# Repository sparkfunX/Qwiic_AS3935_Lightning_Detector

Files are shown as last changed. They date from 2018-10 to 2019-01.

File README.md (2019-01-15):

SparkX Qwiic AS3935 Lightning Detector
========================================

Qwiic AS3925 Lightning Detector (https://www.sparkfun.com/products/15057)

[*SparkX Qwiic AS3935 Lightning Detector (SPX-15057)*](https://www.sparkfun.com/products/15057)

Repository Contents
-------------------

* **/Buzzard Labels** - Silkscreen labels for Qwiic AS3935
* **/Documentation** - Data sheets, additional product information
* **/Hardware** - Eagle design files (.brd, .sch)

Documentation
--------------
* **[Installing an Arduino Library](https://learn.sparkfun.com/tutorials/installing-an-arduino-library/)** - Basic instructions on installing an Arduino library
* **[Library](https://github.com/sparkfun/SparkFun_AS3935_Lightning_Detector_Library)** - Arduino library for the Qwiic AS3935 Lightning Detector

License Information
-------------------

This product is _**open source**_! 

Please review the LICENSE.md file for license information.

If you have any questions or concerns on licensing, please contact techsupport@sparkfun.com.

Please use, reuse, and modify these files as you see fit. Please maintain attribution to SparkFun Electronics and release under the same license.

Distributed as-is; no warranty is given.

- Your friends at SparkFun.

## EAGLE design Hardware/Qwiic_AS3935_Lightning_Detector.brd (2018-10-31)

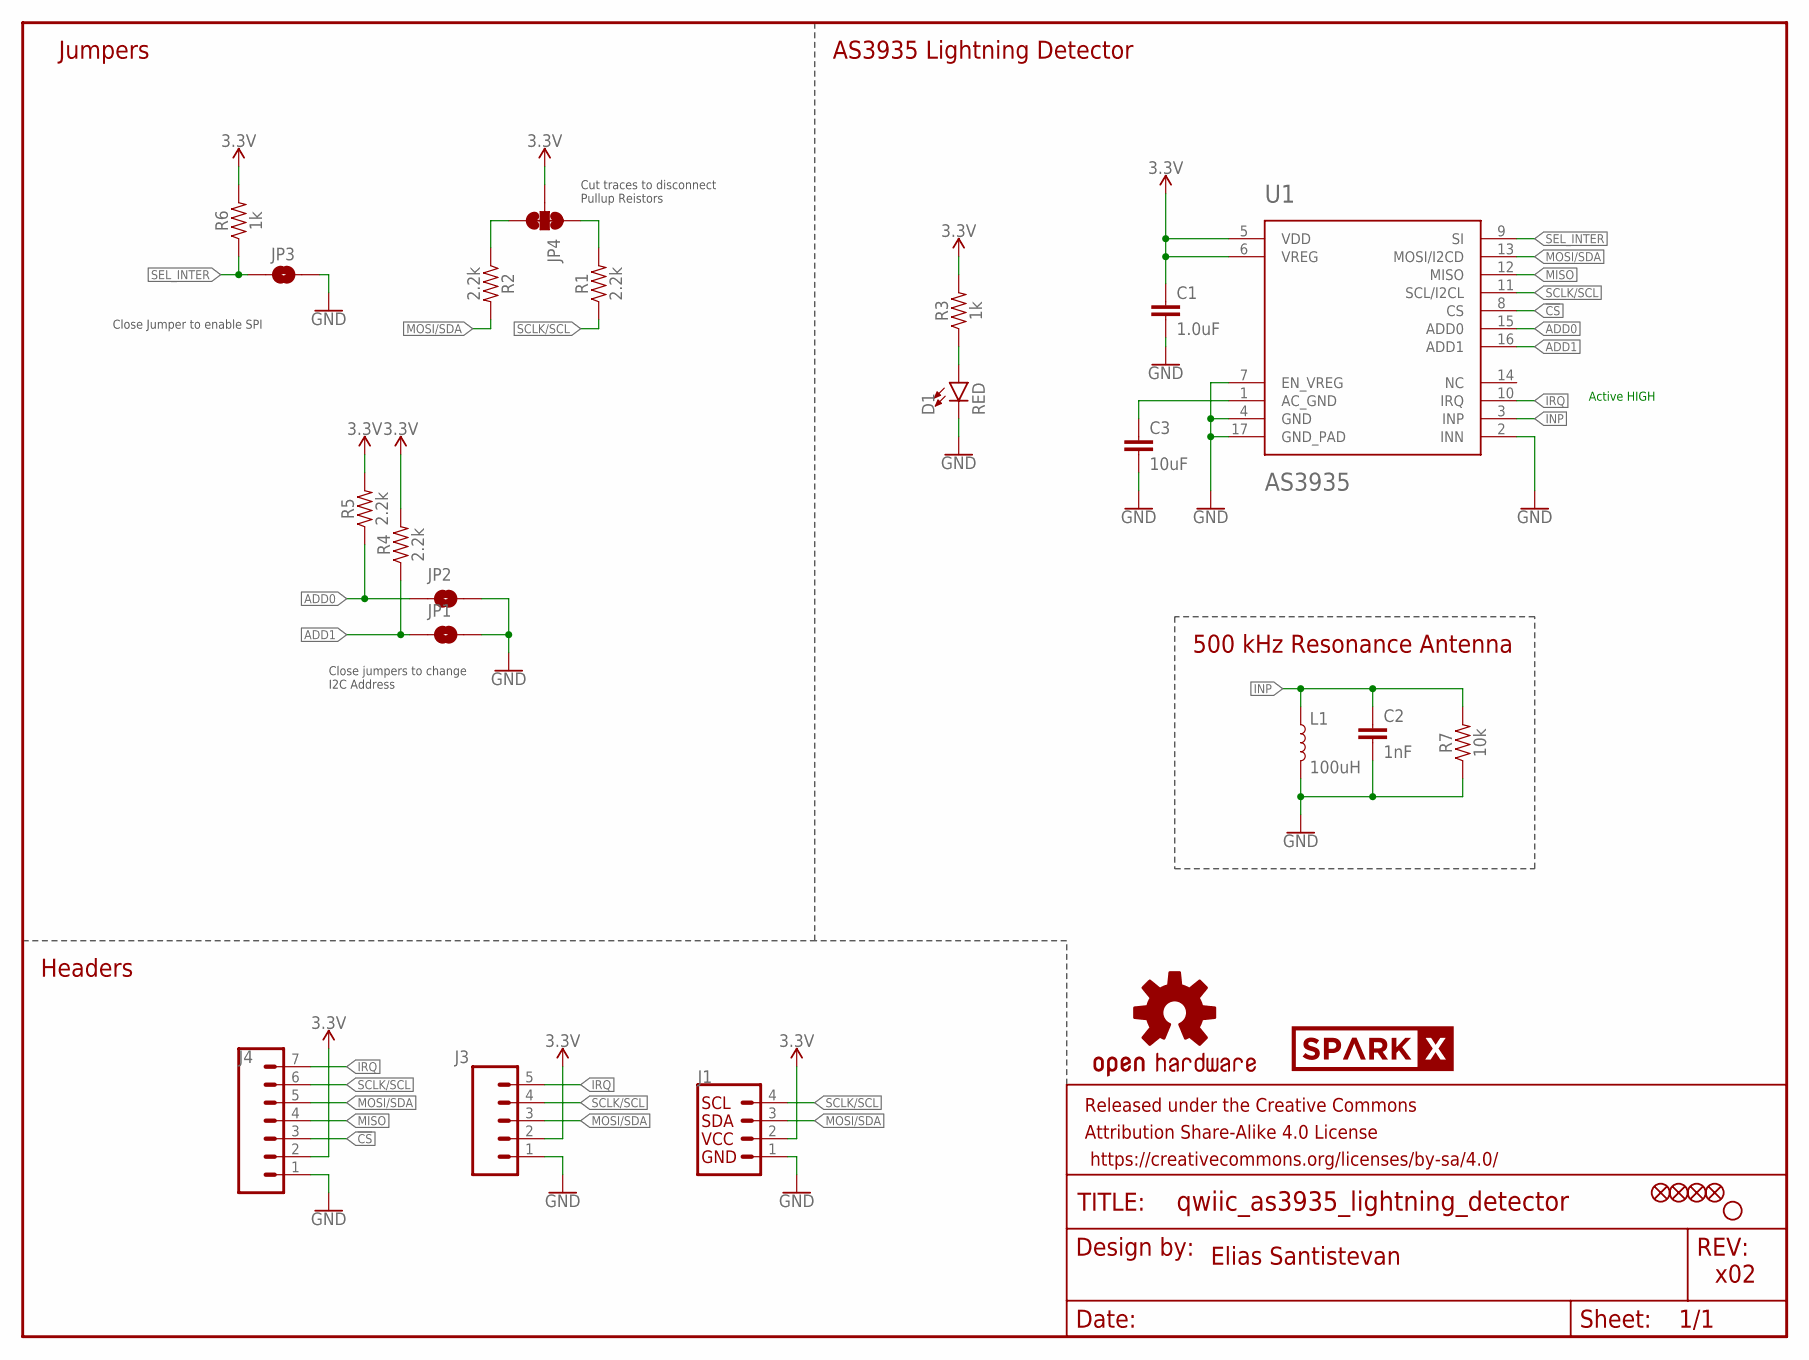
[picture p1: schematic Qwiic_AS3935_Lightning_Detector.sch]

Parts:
C1: 1.0uF; 0603
C2: 1nF; 0603
C3: 10uF; 0603
D1: RED; LED-0603
FD1, FD2, FD3, FD4: FIDUCIAL1X2; FIDUCIAL-1X2
FRAME1: FRAME-LETTER; CREATIVE_COMMONS
H1: STAND-OFFTIGHT; STAND-OFF-TIGHT
J1: QWIIC_CONNECTORJS-1MM; 1X04_1MM_RA
J3: CONN_05NO_SILK; 1X05_NO_SILK
J4: CONN_07NO_SILK; 1X07_NO_SILK
JP1, JP2, JP3: JUMPER-SMT_2_NO_SILK; SMT-JUMPER_2_NO_SILK
JP4: JUMPER-SMT_3_2-NC_TRACE_SILK; SMT-JUMPER_3_2-NC_TRACE_SILK
L1: 100uH; MA5532-AE
LOGO1: OSHW-LOGOS; OSHW-LOGO-S
R1, R2, R4, R5: 2.2k; 0603
R3, R6: 1k; 0603
R7: 10k; 0603
U1: AS3935; 16LD_MLPQ
U$1: SPARKX-LOGO2; SPARKX-TINY

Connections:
3.3V: C1.1, J1.2, J3.2, J4.2, JP4.2, R3.2, R4.2, R5.2, R6.2, U1.5 (VDD), U1.6 (VREG)
!CS: J4.3, U1.8 (CS)
ADD0: JP2.1, R5.1, U1.15 (ADD0)
ADD1: JP1.1, R4.1, U1.16 (ADD1)
GND: C1.2, C2.2, C3.2, D1.C, J1.1, J3.1, J4.1, JP1.2, JP2.2, JP3.2, L1.2, R7.1, U1.2 (INN), U1.4 (GND), U1.7 (EN_VREG), U1.17 (GND_PAD)
INP: C2.1, L1.1, R7.2, U1.3 (INP)
IRQ: J3.5, J4.7, U1.10 (IRQ)
MISO: J4.4, U1.12 (MISO)
MOSI/SDA: J1.3, J3.3, J4.5, R2.2, U1.13 (MOSI/I2CD)
unnamed: D1.A, R3.1
unnamed: C3.1, U1.1 (AC_GND)
unnamed: JP4.1, R1.2
unnamed: JP4.3, R2.1
SCLK/SCL: J1.4, J3.4, J4.6, R1.1, U1.11 (SCL/I2CL)
SEL_INTER: JP3.1, R6.1, U1.9 (SI)

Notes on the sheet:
Elias Santistevan
x02
Active HIGH
AS3935 Lightning Detector
Jumpers
Headers
500 kHz Resonance Antenna
Close Jumper to enable SPI
Cut traces to disconnect Pullup Reistors
Close jumpers to change I2C Address

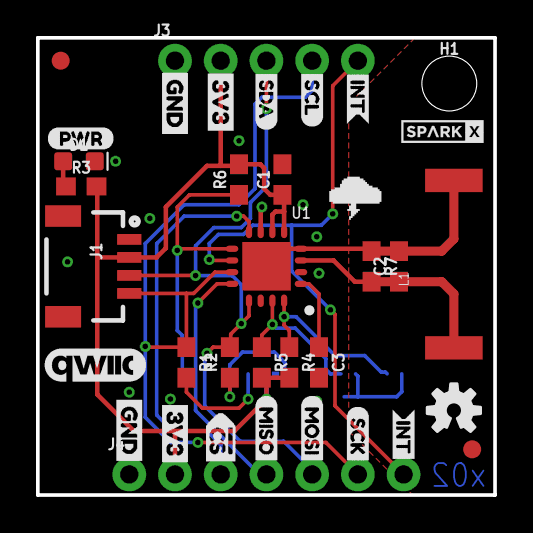
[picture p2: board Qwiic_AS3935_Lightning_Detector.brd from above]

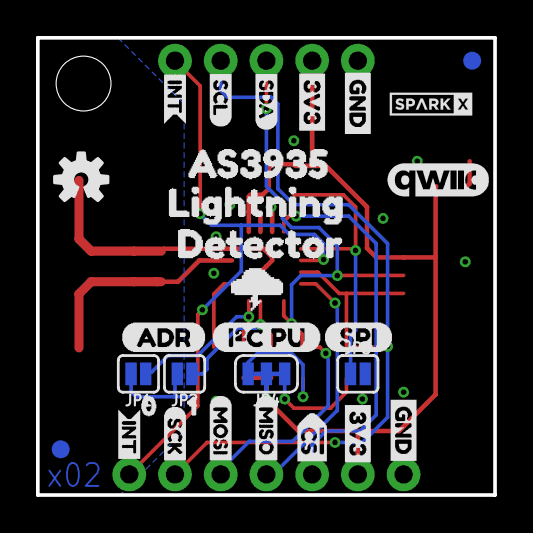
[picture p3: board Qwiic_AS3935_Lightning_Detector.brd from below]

Board: 2 copper layers, 25.4 x 25.4 mm, 67 parts (30 on the bottom side), 15 nets.

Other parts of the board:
U$2: SPARKX-TINY
U$3, U$4: QWIIC_COPYRIGHT_SMALL
U$5, U$40: ##0
U$6: AS39350
U$7: LIGHTNING0
U$8, U$9, U$10, U$38: GND-03
U$11: CS#-<]-04
U$12, U$13: MISO-(]-03
U$14, U$15, U$24, U$29: INT0
U$16, U$22: MOSI-(]-03
U$17, U$18, U$20, U$21: 3V3-03
U$19, U$23: SCK-(]-03
U$25, U$26: SDA0
U$27, U$28: SCL0
U$30: #CS0
U$31: OSHW-LOGO-S
U$32: PWR-()-03
U$33: ADR-()-04
U$34: I#C_PU0
U$35: SPI0
U$36: 10
U$37: 00
U$39: DETECTOR0

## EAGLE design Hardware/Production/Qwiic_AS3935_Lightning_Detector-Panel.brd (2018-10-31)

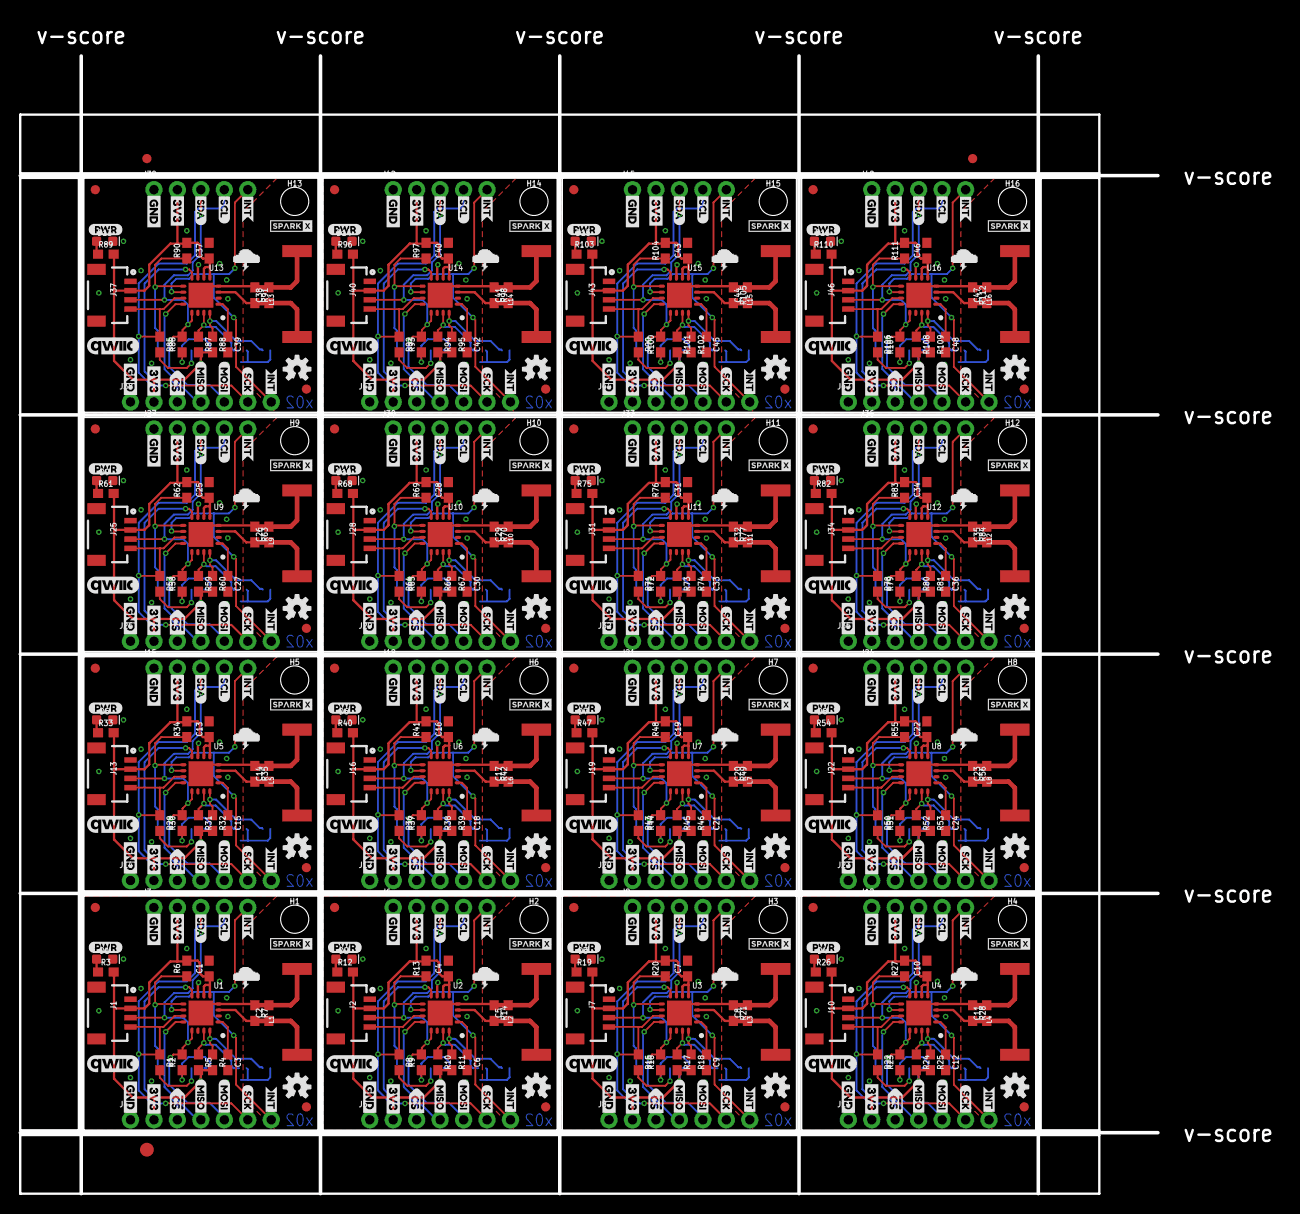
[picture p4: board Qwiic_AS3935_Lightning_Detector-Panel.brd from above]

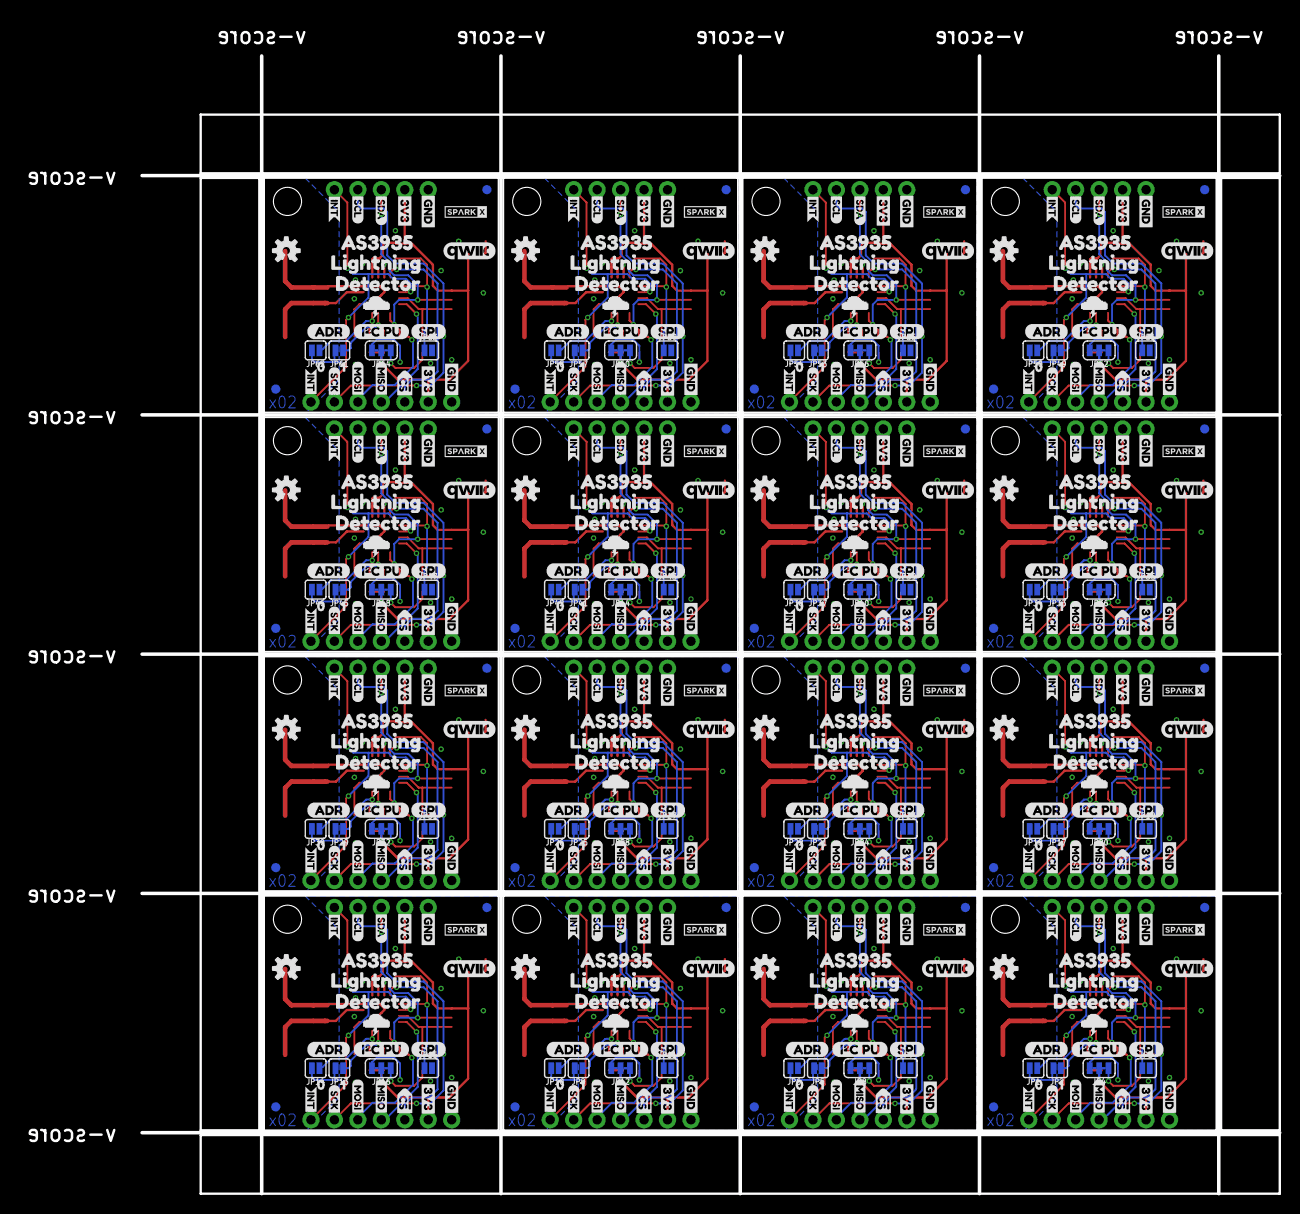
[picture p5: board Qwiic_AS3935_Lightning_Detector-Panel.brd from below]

Board: 2 copper layers, 123.2 x 123.2 mm, 1059 parts (480 on the bottom side), 240 nets.

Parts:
C1, C4, C7, C10, C13, C16, C19, C22, C25, C28, C31, C34, C37, C40, C43, C46: 1.0uF; 0603
C2, C5, C8, C11, C14, C17, C20, C23, C26, C29, C32, C35, C38, C41, C44, C47: 1nF; 0603
C3, C6, C9, C12, C15, C18, C21, C24, C27, C30, C33, C36, C39, C42, C45, C48: 10uF; 0603
D1, D2, D3, D4, D5, D6, D7, D8, D9, D10, D11, D12, D13, D14, D15, D16: RED; LED-0603
E$1, E$2: FIDUCIAL-1X2
E$3: FIDUCIAL-1.5X3
FD1, FD2, FD3, FD4, FD5, FD6, FD7, FD8, FD9, FD10, FD11, FD12, FD13, FD14, FD15, FD16, FD17, FD18, FD19, FD20, FD21, FD22, FD23, FD24, FD25, FD26, FD27, FD28, FD29, FD30, FD31, FD32, FD33, FD34, FD35, FD36, FD37, FD38, FD39, FD40, FD41, FD42, FD43, FD44, FD45, FD46, FD47, FD48, FD49, FD50, FD51, FD52, FD53, FD54, FD55, FD56, FD57, FD58, FD59, FD60, FD61, FD62, FD63, FD64: FIDUCIAL1X2; FIDUCIAL-1X2
H1, H2, H3, H4, H5, H6, H7, H8, H9, H10, H11, H12, H13, H14, H15, H16: STAND-OFFTIGHT; STAND-OFF-TIGHT
J1, J2, J7, J10, J13, J16, J19, J22, J25, J28, J31, J34, J37, J40, J43, J46: 1X04_1MM_RA
J3, J6, J9, J12, J15, J18, J21, J24, J27, J30, J33, J36, J39, J42, J45, J48: 1X05_NO_SILK
J4, J5, J8, J11, J14, J17, J20, J23, J26, J29, J32, J35, J38, J41, J44, J47: 1X07_NO_SILK
JP1, JP2, JP3, JP5, JP6, JP7, JP9, JP10, JP11, JP13, JP14, JP15, JP17, JP18, JP19, JP21, JP22, JP23, JP25, JP26, JP27, JP29, JP30, JP31, JP33, JP34, JP35, JP37, JP38, JP39, JP41, JP42, JP43, JP45, JP46, JP47, JP49, JP50, JP51, JP53, JP54, JP55, JP57, JP58, JP59, JP61, JP62, JP63: JUMPER-SMT_2_NO_SILK; SMT-JUMPER_2_NO_SILK
JP4, JP8, JP12, JP16, JP20, JP24, JP28, JP32, JP36, JP40, JP44, JP48, JP52, JP56, JP60, JP64: JUMPER-SMT_3_2-NC_TRACE_SILK; SMT-JUMPER_3_2-NC_TRACE_SILK
L1, L2, L3, L4, L5, L6, L7, L8, L9, L10, L11, L12, L13, L14, L15, L16: 100uH; MA5532-AE
LOGO1, LOGO2, LOGO3, LOGO4, LOGO5, LOGO6, LOGO7, LOGO8, LOGO9, LOGO10, LOGO11, LOGO12, LOGO13, LOGO14, LOGO15, LOGO16: OSHW-LOGOS; OSHW-LOGO-S
R1, R2, R4, R5, R8, R9, R10, R11, R15, R16, R17, R18, R22, R23, R24, R25, R29, R30, R31, R32, R36, R37, R38, R39, R43, R44, R45, R46, R50, R51, R52, R53, R57, R58, R59, R60, R64, R65, R66, R67, R71, R72, R73, R74, R78, R79, R80, R81, R85, R86, R87, R88, R92, R93, R94, R95, R99, R100, R101, R102, R106, R107, R108, R109: 2.2k; 0603
R3, R6, R12, R13, R19, R20, R26, R27, R33, R34, R40, R41, R47, R48, R54, R55, R61, R62, R68, R69, R75, R76, R82, R83, R89, R90, R96, R97, R103, R104, R110, R111: 1k; 0603
R7, R14, R21, R28, R35, R42, R49, R56, R63, R70, R77, R84, R91, R98, R105, R112: 10k; 0603
U1, U2, U3, U4, U5, U6, U7, U8, U9, U10, U11, U12, U13, U14, U15, U16: AS3935; 16LD_MLPQ
U$1, U$41, U$81, U$121, U$161, U$201, U$241, U$281, U$321, U$361, U$401, U$441, U$481, U$521, U$561, U$601: SPARKX-LOGO2; SPARKX-TINY
U$2, U$42, U$82, U$122, U$162, U$202, U$242, U$282, U$322, U$362, U$402, U$442, U$482, U$522, U$562, U$602: SPARKX-TINY
U$3, U$4, U$43, U$44, U$83, U$84, U$123, U$124, U$163, U$164, U$203, U$204, U$243, U$244, U$283, U$284, U$323, U$324, U$363, U$364, U$403, U$404, U$443, U$444, U$483, U$484, U$523, U$524, U$563, U$564, U$603, U$604: QWIIC_COPYRIGHT_SMALL
U$5, U$40, U$67, U$68, U$107, U$108, U$147, U$148, U$187, U$188, U$227, U$228, U$267, U$268, U$307, U$308, U$347, U$348, U$387, U$388, U$427, U$428, U$467, U$468, U$507, U$508, U$547, U$548, U$587, U$588, U$627, U$628: ##0
U$6, U$64, U$104, U$144, U$184, U$224, U$264, U$304, U$344, U$384, U$424, U$464, U$504, U$544, U$584, U$624: AS39350
U$7, U$65, U$105, U$145, U$185, U$225, U$265, U$305, U$345, U$385, U$425, U$465, U$505, U$545, U$585, U$625: LIGHTNING0
U$8, U$9, U$10, U$38, U$45, U$46, U$63, U$69, U$85, U$86, U$103, U$109, U$125, U$126, U$143, U$149, U$165, U$166, U$183, U$189, U$205, U$206, U$223, U$229, U$245, U$246, U$263, U$269, U$285, U$286, U$303, U$309, U$325, U$326, U$343, U$349, U$365, U$366, U$383, U$389, U$405, U$406, U$423, U$429, U$445, U$446, U$463, U$469, U$485, U$486, U$503, U$509, U$525, U$526, U$543, U$549, U$565, U$566, U$583, U$589, U$605, U$606, U$623, U$629: GND-03
U$11, U$70, U$110, U$150, U$190, U$230, U$270, U$310, U$350, U$390, U$430, U$470, U$510, U$550, U$590, U$630: CS#-<]-04
U$12, U$13, U$47, U$72, U$87, U$112, U$127, U$152, U$167, U$192, U$207, U$232, U$247, U$272, U$287, U$312, U$327, U$352, U$367, U$392, U$407, U$432, U$447, U$472, U$487, U$512, U$527, U$552, U$567, U$592, U$607, U$632: MISO-(]-03
U$14, U$15, U$24, U$29, U$74, U$75, U$76, U$77, U$114, U$115, U$116, U$117, U$154, U$155, U$156, U$157, U$194, U$195, U$196, U$197, U$234, U$235, U$236, U$237, U$274, U$275, U$276, U$277, U$314, U$315, U$316, U$317, U$354, U$355, U$356, U$357, U$394, U$395, U$396, U$397, U$434, U$435, U$436, U$437, U$474, U$475, U$476, U$477, U$514, U$515, U$516, U$517, U$554, U$555, U$556, U$557, U$594, U$595, U$596, U$597, U$634, U$635, U$636, U$637: INT0
U$16, U$22, U$71, U$78, U$111, U$118, U$151, U$158, U$191, U$198, U$231, U$238, U$271, U$278, U$311, U$318, U$351, U$358, U$391, U$398, U$431, U$438, U$471, U$478, U$511, U$518, U$551, U$558, U$591, U$598, U$631, U$638: MOSI-(]-03
U$17, U$18, U$20, U$21, U$48, U$49, U$50, U$51, U$88, U$89, U$90, U$91, U$128, U$129, U$130, U$131, U$168, U$169, U$170, U$171, U$208, U$209, U$210, U$211, U$248, U$249, U$250, U$251, U$288, U$289, U$290, U$291, U$328, U$329, U$330, U$331, U$368, U$369, U$370, U$371, U$408, U$409, U$410, U$411, U$448, U$449, U$450, U$451, U$488, U$489, U$490, U$491, U$528, U$529, U$530, U$531, U$568, U$569, U$570, U$571, U$608, U$609, U$610, U$611: 3V3-03
U$19, U$23, U$73, U$79, U$113, U$119, U$153, U$159, U$193, U$199, U$233, U$239, U$273, U$279, U$313, U$319, U$353, U$359, U$393, U$399, U$433, U$439, U$473, U$479, U$513, U$519, U$553, U$559, U$593, U$599, U$633, U$639: SCK-(]-03
U$25, U$26, U$52, U$53, U$92, U$93, U$132, U$133, U$172, U$173, U$212, U$213, U$252, U$253, U$292, U$293, U$332, U$333, U$372, U$373, U$412, U$413, U$452, U$453, U$492, U$493, U$532, U$533, U$572, U$573, U$612, U$613: SDA0
U$27, U$28, U$54, U$55, U$94, U$95, U$134, U$135, U$174, U$175, U$214, U$215, U$254, U$255, U$294, U$295, U$334, U$335, U$374, U$375, U$414, U$415, U$454, U$455, U$494, U$495, U$534, U$535, U$574, U$575, U$614, U$615: SCL0
U$30, U$80, U$120, U$160, U$200, U$240, U$280, U$320, U$360, U$400, U$440, U$480, U$520, U$560, U$600, U$640: #CS0
U$31, U$56, U$96, U$136, U$176, U$216, U$256, U$296, U$336, U$376, U$416, U$456, U$496, U$536, U$576, U$616: OSHW-LOGO-S
U$32, U$57, U$97, U$137, U$177, U$217, U$257, U$297, U$337, U$377, U$417, U$457, U$497, U$537, U$577, U$617: PWR-()-03
U$33, U$58, U$98, U$138, U$178, U$218, U$258, U$298, U$338, U$378, U$418, U$458, U$498, U$538, U$578, U$618: ADR-()-04
U$34, U$59, U$99, U$139, U$179, U$219, U$259, U$299, U$339, U$379, U$419, U$459, U$499, U$539, U$579, U$619: I#C_PU0
U$35, U$60, U$100, U$140, U$180, U$220, U$260, U$300, U$340, U$380, U$420, U$460, U$500, U$540, U$580, U$620: SPI0
U$36, U$61, U$101, U$141, U$181, U$221, U$261, U$301, U$341, U$381, U$421, U$461, U$501, U$541, U$581, U$621: 10
U$37, U$62, U$102, U$142, U$182, U$222, U$262, U$302, U$342, U$382, U$422, U$462, U$502, U$542, U$582, U$622: 00
U$39, U$66, U$106, U$146, U$186, U$226, U$266, U$306, U$346, U$386, U$426, U$466, U$506, U$546, U$586, U$626: DETECTOR0

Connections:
3.3V: C1.1, J1.2, J3.2, J4.2, JP4.2, R3.2, R4.2, R5.2, R6.2, U1.5, U1.6
3.3V1: C4.1, J2.2, J5.2, J6.2, JP8.2, R10.2, R11.2, R12.2, R13.2, U2.5, U2.6
3.3V2: C7.1, J7.2, J8.2, J9.2, JP12.2, R17.2, R18.2, R19.2, R20.2, U3.5, U3.6
3.3V3: C10.1, J10.2, J11.2, J12.2, JP16.2, R24.2, R25.2, R26.2, R27.2, U4.5, U4.6
3.3V4: C13.1, J13.2, J14.2, J15.2, JP20.2, R31.2, R32.2, R33.2, R34.2, U5.5, U5.6
3.3V5: C16.1, J16.2, J17.2, J18.2, JP24.2, R38.2, R39.2, R40.2, R41.2, U6.5, U6.6
3.3V6: C19.1, J19.2, J20.2, J21.2, JP28.2, R45.2, R46.2, R47.2, R48.2, U7.5, U7.6
3.3V7: C22.1, J22.2, J23.2, J24.2, JP32.2, R52.2, R53.2, R54.2, R55.2, U8.5, U8.6
3.3V8: C25.1, J25.2, J26.2, J27.2, JP36.2, R59.2, R60.2, R61.2, R62.2, U9.5, U9.6
3.3V9: C28.1, J28.2, J29.2, J30.2, JP40.2, R66.2, R67.2, R68.2, R69.2, U10.5, U10.6
3.3V10: C31.1, J31.2, J32.2, J33.2, JP44.2, R73.2, R74.2, R75.2, R76.2, U11.5, U11.6
3.3V11: C34.1, J34.2, J35.2, J36.2, JP48.2, R80.2, R81.2, R82.2, R83.2, U12.5, U12.6
3.3V12: C37.1, J37.2, J38.2, J39.2, JP52.2, R87.2, R88.2, R89.2, R90.2, U13.5, U13.6
3.3V13: C40.1, J40.2, J41.2, J42.2, JP56.2, R94.2, R95.2, R96.2, R97.2, U14.5, U14.6
3.3V14: C43.1, J43.2, J44.2, J45.2, JP60.2, R101.2, R102.2, R103.2, R104.2, U15.5, U15.6
3.3V15: C46.1, J46.2, J47.2, J48.2, JP64.2, R108.2, R109.2, R110.2, R111.2, U16.5, U16.6
!CS: J4.3, U1.8
!CS1: J5.3, U2.8
!CS2: J8.3, U3.8
!CS3: J11.3, U4.8
!CS4: J14.3, U5.8
!CS5: J17.3, U6.8
!CS6: J20.3, U7.8
!CS7: J23.3, U8.8
!CS8: J26.3, U9.8
!CS9: J29.3, U10.8
!CS10: J32.3, U11.8
!CS11: J35.3, U12.8
!CS12: J38.3, U13.8
!CS13: J41.3, U14.8
!CS14: J44.3, U15.8
!CS15: J47.3, U16.8
ADD0: JP2.1, R5.1, U1.15
ADD1: JP1.1, R4.1, U1.16
ADD2: JP5.1, R10.1, U2.15
ADD3: JP6.1, R11.1, U2.16
ADD4: JP9.1, R17.1, U3.15
ADD5: JP10.1, R18.1, U3.16
ADD6: JP13.1, R24.1, U4.15
ADD7: JP14.1, R25.1, U4.16
ADD8: JP17.1, R31.1, U5.15
ADD9: JP18.1, R32.1, U5.16
ADD10: JP21.1, R38.1, U6.15
ADD11: JP22.1, R39.1, U6.16
ADD12: JP25.1, R45.1, U7.15
ADD13: JP26.1, R46.1, U7.16
ADD14: JP29.1, R52.1, U8.15
ADD15: JP30.1, R53.1, U8.16
ADD16: JP33.1, R59.1, U9.15
ADD17: JP34.1, R60.1, U9.16
ADD18: JP37.1, R66.1, U10.15
ADD19: JP38.1, R67.1, U10.16
ADD20: JP41.1, R73.1, U11.15
ADD21: JP42.1, R74.1, U11.16
ADD22: JP45.1, R80.1, U12.15
ADD23: JP46.1, R81.1, U12.16
ADD24: JP49.1, R87.1, U13.15
ADD25: JP50.1, R88.1, U13.16
ADD26: JP53.1, R94.1, U14.15
ADD27: JP54.1, R95.1, U14.16
ADD28: JP57.1, R101.1, U15.15
ADD29: JP58.1, R102.1, U15.16
ADD30: JP61.1, R108.1, U16.15
ADD31: JP62.1, R109.1, U16.16
GND: C1.2, C2.2, C3.2, D1.C, J1.1, J3.1, J4.1, JP1.2, JP2.2, JP3.2, L1.2, R7.1, U1.2, U1.4, U1.7, U1.17
GND1: C4.2, C5.2, C6.2, D2.C, J2.1, J5.1, J6.1, JP5.2, JP6.2, JP7.2, L2.2, R14.1, U2.2, U2.4, U2.7, U2.17
GND2: C7.2, C8.2, C9.2, D3.C, J7.1, J8.1, J9.1, JP9.2, JP10.2, JP11.2, L3.2, R21.1, U3.2, U3.4, U3.7, U3.17
GND3: C10.2, C11.2, C12.2, D4.C, J10.1, J11.1, J12.1, JP13.2, JP14.2, JP15.2, L4.2, R28.1, U4.2, U4.4, U4.7, U4.17
GND4: C13.2, C14.2, C15.2, D5.C, J13.1, J14.1, J15.1, JP17.2, JP18.2, JP19.2, L5.2, R35.1, U5.2, U5.4, U5.7, U5.17
GND5: C16.2, C17.2, C18.2, D6.C, J16.1, J17.1, J18.1, JP21.2, JP22.2, JP23.2, L6.2, R42.1, U6.2, U6.4, U6.7, U6.17
GND6: C19.2, C20.2, C21.2, D7.C, J19.1, J20.1, J21.1, JP25.2, JP26.2, JP27.2, L7.2, R49.1, U7.2, U7.4, U7.7, U7.17
GND7: C22.2, C23.2, C24.2, D8.C, J22.1, J23.1, J24.1, JP29.2, JP30.2, JP31.2, L8.2, R56.1, U8.2, U8.4, U8.7, U8.17
GND8: C25.2, C26.2, C27.2, D9.C, J25.1, J26.1, J27.1, JP33.2, JP34.2, JP35.2, L9.2, R63.1, U9.2, U9.4, U9.7, U9.17
GND9: C28.2, C29.2, C30.2, D10.C, J28.1, J29.1, J30.1, JP37.2, JP38.2, JP39.2, L10.2, R70.1, U10.2, U10.4, U10.7, U10.17
GND10: C31.2, C32.2, C33.2, D11.C, J31.1, J32.1, J33.1, JP41.2, JP42.2, JP43.2, L11.2, R77.1, U11.2, U11.4, U11.7, U11.17
GND11: C34.2, C35.2, C36.2, D12.C, J34.1, J35.1, J36.1, JP45.2, JP46.2, JP47.2, L12.2, R84.1, U12.2, U12.4, U12.7, U12.17
GND12: C37.2, C38.2, C39.2, D13.C, J37.1, J38.1, J39.1, JP49.2, JP50.2, JP51.2, L13.2, R91.1, U13.2, U13.4, U13.7, U13.17
GND13: C40.2, C41.2, C42.2, D14.C, J40.1, J41.1, J42.1, JP53.2, JP54.2, JP55.2, L14.2, R98.1, U14.2, U14.4, U14.7, U14.17
GND14: C43.2, C44.2, C45.2, D15.C, J43.1, J44.1, J45.1, JP57.2, JP58.2, JP59.2, L15.2, R105.1, U15.2, U15.4, U15.7, U15.17
GND15: C46.2, C47.2, C48.2, D16.C, J46.1, J47.1, J48.1, JP61.2, JP62.2, JP63.2, L16.2, R112.1, U16.2, U16.4, U16.7, U16.17
INP: C2.1, L1.1, R7.2, U1.3
INP1: C5.1, L2.1, R14.2, U2.3
INP2: C8.1, L3.1, R21.2, U3.3
INP3: C11.1, L4.1, R28.2, U4.3
INP4: C14.1, L5.1, R35.2, U5.3
INP5: C17.1, L6.1, R42.2, U6.3
INP6: C20.1, L7.1, R49.2, U7.3
INP7: C23.1, L8.1, R56.2, U8.3
INP8: C26.1, L9.1, R63.2, U9.3
INP9: C29.1, L10.1, R70.2, U10.3
INP10: C32.1, L11.1, R77.2, U11.3
INP11: C35.1, L12.1, R84.2, U12.3
INP12: C38.1, L13.1, R91.2, U13.3
INP13: C41.1, L14.1, R98.2, U14.3
INP14: C44.1, L15.1, R105.2, U15.3
INP15: C47.1, L16.1, R112.2, U16.3
IRQ: J3.5, J4.7, U1.10
IRQ1: J5.7, J6.5, U2.10
IRQ2: J8.7, J9.5, U3.10
IRQ3: J11.7, J12.5, U4.10
IRQ4: J14.7, J15.5, U5.10
IRQ5: J17.7, J18.5, U6.10
IRQ6: J20.7, J21.5, U7.10
IRQ7: J23.7, J24.5, U8.10
IRQ8: J26.7, J27.5, U9.10
IRQ9: J29.7, J30.5, U10.10
IRQ10: J32.7, J33.5, U11.10
IRQ11: J35.7, J36.5, U12.10
IRQ12: J38.7, J39.5, U13.10
IRQ13: J41.7, J42.5, U14.10
IRQ14: J44.7, J45.5, U15.10
IRQ15: J47.7, J48.5, U16.10
MISO: J4.4, U1.12
MISO1: J5.4, U2.12
MISO2: J8.4, U3.12
MISO3: J11.4, U4.12
MISO4: J14.4, U5.12
MISO5: J17.4, U6.12
MISO6: J20.4, U7.12
MISO7: J23.4, U8.12
MISO8: J26.4, U9.12
MISO9: J29.4, U10.12
MISO10: J32.4, U11.12
MISO11: J35.4, U12.12
MISO12: J38.4, U13.12
MISO13: J41.4, U14.12
MISO14: J44.4, U15.12
MISO15: J47.4, U16.12
MOSI/SDA: J1.3, J3.3, J4.5, R2.2, U1.13
MOSI/SDA1: J2.3, J5.5, J6.3, R9.2, U2.13
MOSI/SDA2: J7.3, J8.5, J9.3, R16.2, U3.13
MOSI/SDA3: J10.3, J11.5, J12.3, R23.2, U4.13
MOSI/SDA4: J13.3, J14.5, J15.3, R30.2, U5.13
MOSI/SDA5: J16.3, J17.5, J18.3, R37.2, U6.13
MOSI/SDA6: J19.3, J20.5, J21.3, R44.2, U7.13
MOSI/SDA7: J22.3, J23.5, J24.3, R51.2, U8.13
MOSI/SDA8: J25.3, J26.5, J27.3, R58.2, U9.13
MOSI/SDA9: J28.3, J29.5, J30.3, R65.2, U10.13
MOSI/SDA10: J31.3, J32.5, J33.3, R72.2, U11.13
MOSI/SDA11: J34.3, J35.5, J36.3, R79.2, U12.13
MOSI/SDA12: J37.3, J38.5, J39.3, R86.2, U13.13
MOSI/SDA13: J40.3, J41.5, J42.3, R93.2, U14.13
MOSI/SDA14: J43.3, J44.5, J45.3, R100.2, U15.13
MOSI/SDA15: J46.3, J47.5, J48.3, R107.2, U16.13
unnamed: D1.A, R3.1
unnamed: C3.1, U1.1
unnamed: JP4.1, R1.2
unnamed: JP4.3, R2.1
unnamed: D2.A, R12.1
unnamed: C6.1, U2.1
unnamed: JP8.1, R8.2
unnamed: JP8.3, R9.1
unnamed: D3.A, R19.1
unnamed: C9.1, U3.1
unnamed: JP12.1, R15.2
unnamed: JP12.3, R16.1
unnamed: D4.A, R26.1
unnamed: C12.1, U4.1
unnamed: JP16.1, R22.2
unnamed: JP16.3, R23.1
unnamed: D5.A, R33.1
unnamed: C15.1, U5.1
unnamed: JP20.1, R29.2
unnamed: JP20.3, R30.1
unnamed: D6.A, R40.1
unnamed: C18.1, U6.1
unnamed: JP24.1, R36.2
unnamed: JP24.3, R37.1
unnamed: D7.A, R47.1
unnamed: C21.1, U7.1
unnamed: JP28.1, R43.2
unnamed: JP28.3, R44.1
unnamed: D8.A, R54.1
unnamed: C24.1, U8.1
unnamed: JP32.1, R50.2
unnamed: JP32.3, R51.1
unnamed: D9.A, R61.1
unnamed: C27.1, U9.1
unnamed: JP36.1, R57.2
unnamed: JP36.3, R58.1
unnamed: D10.A, R68.1
unnamed: C30.1, U10.1
unnamed: JP40.1, R64.2
unnamed: JP40.3, R65.1
unnamed: D11.A, R75.1
unnamed: C33.1, U11.1
unnamed: JP44.1, R71.2
unnamed: JP44.3, R72.1
unnamed: D12.A, R82.1
unnamed: C36.1, U12.1
unnamed: JP48.1, R78.2
unnamed: JP48.3, R79.1
unnamed: D13.A, R89.1
unnamed: C39.1, U13.1
unnamed: JP52.1, R85.2
unnamed: JP52.3, R86.1
unnamed: D14.A, R96.1
unnamed: C42.1, U14.1
unnamed: JP56.1, R92.2
unnamed: JP56.3, R93.1
unnamed: D15.A, R103.1
unnamed: C45.1, U15.1
unnamed: JP60.1, R99.2
unnamed: JP60.3, R100.1
unnamed: D16.A, R110.1
unnamed: C48.1, U16.1
unnamed: JP64.1, R106.2
unnamed: JP64.3, R107.1
SCLK/SCL: J1.4, J3.4, J4.6, R1.1, U1.11
SCLK/SCL1: J2.4, J5.6, J6.4, R8.1, U2.11
SCLK/SCL2: J7.4, J8.6, J9.4, R15.1, U3.11
SCLK/SCL3: J10.4, J11.6, J12.4, R22.1, U4.11
SCLK/SCL4: J13.4, J14.6, J15.4, R29.1, U5.11
SCLK/SCL5: J16.4, J17.6, J18.4, R36.1, U6.11
SCLK/SCL6: J19.4, J20.6, J21.4, R43.1, U7.11
SCLK/SCL7: J22.4, J23.6, J24.4, R50.1, U8.11
SCLK/SCL8: J25.4, J26.6, J27.4, R57.1, U9.11
SCLK/SCL9: J28.4, J29.6, J30.4, R64.1, U10.11
SCLK/SCL10: J31.4, J32.6, J33.4, R71.1, U11.11
SCLK/SCL11: J34.4, J35.6, J36.4, R78.1, U12.11
SCLK/SCL12: J37.4, J38.6, J39.4, R85.1, U13.11
SCLK/SCL13: J40.4, J41.6, J42.4, R92.1, U14.11
SCLK/SCL14: J43.4, J44.6, J45.4, R99.1, U15.11
SCLK/SCL15: J46.4, J47.6, J48.4, R106.1, U16.11
SEL_INTER: JP3.1, R6.1, U1.9
SEL_INTER1: JP7.1, R13.1, U2.9
SEL_INTER2: JP11.1, R20.1, U3.9
SEL_INTER3: JP15.1, R27.1, U4.9
SEL_INTER4: JP19.1, R34.1, U5.9
SEL_INTER5: JP23.1, R41.1, U6.9
SEL_INTER6: JP27.1, R48.1, U7.9
SEL_INTER7: JP31.1, R55.1, U8.9
SEL_INTER8: JP35.1, R62.1, U9.9
SEL_INTER9: JP39.1, R69.1, U10.9
SEL_INTER10: JP43.1, R76.1, U11.9
SEL_INTER11: JP47.1, R83.1, U12.9
SEL_INTER12: JP51.1, R90.1, U13.9
SEL_INTER13: JP55.1, R97.1, U14.9
SEL_INTER14: JP59.1, R104.1, U15.9
SEL_INTER15: JP63.1, R111.1, U16.9

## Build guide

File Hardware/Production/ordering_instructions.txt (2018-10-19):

panel size, 117x117mm
PCB thickness, 1.6mm
number of layers, 2
soldermask color, Black
silkscreen color, White
oz copper, 1oz
finish, HASL lead free
stencils, top+bottom
pcs per panel, 16

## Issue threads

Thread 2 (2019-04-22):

Support for other architectures

SouleMakes, 2019-04-22:
Hey everyone,
First, thank you for this library.
Is there is any movement to expand this library for use with other common microprocessor architectures? I have an issue that I suspect is architecture based.
I am, specifically, trying to use this as part of an existing weather station run on an ESP32 processor and getting a bunch of compile issues.

`SparkFun_AS3935 lightning(AS3935_ADDR);`

Returns error:
_"WeatherStation_FeatherHUZZAH:40:38: error: invalid conversion from 'int' to 'i2cAddress {aka SF_AS3935_I2C_ADDRESS}' [-fpermissive]"_

Suspect this is because I'm not on AVR-based board but rather a Adafruit Feather HUZZAH 32 (ESP32).

Thank you.

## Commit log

2018-10-19 Initial Commit x01
    [Qwiic_AS3935_Lightning_Detector.brd, Qwiic_AS3935_Lightning_Detector.sch]
2018-10-19 Library update, small changeds to PCB
    [Qwiic_AS3935_Lightning_Detector.brd]
2018-10-19 Panel created
    [Qwiic_AS3935_Lightning_Detector-Panel.GBL, Qwiic_AS3935_Lightning_Detector-Panel.GBO, Qwiic_AS3935_Lightning_Detector-Panel.GBS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]
2018-10-19 Fixed AS3935 SKU in library
    [Qwiic_AS3935_Lightning_Detector.brd, Qwiic_AS3935_Lightning_Detector.sch]
2018-10-31 Version x02 Exposed pad underneath was not connected to ground, coil package was incorrect.
    [Qwiic_AS3935_Lightning_Detector-Panel.brd, Qwiic_AS3935_Lightning_Detector.brd, Qwiic_AS3935_Lightning_Detector.sch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]
2018-10-31 One more time
    [Qwiic_AS3935_Lightning_Detector-Panel.GBL, Qwiic_AS3935_Lightning_Detector-Panel.GBO, Qwiic_AS3935_Lightning_Detector-Panel.GBS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]
2019-01-08 Updates README and deletes unnecssary production files.
    [Qwiic_AS3935_Lightning_Detector-Panel.GBL, Qwiic_AS3935_Lightning_Detector-Panel.GBO, Qwiic_AS3935_Lightning_Detector-Panel.GBS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]
2019-01-09 Update and rename Readme.md to README.md
    - Link Arduino library and how to install an Arduino library.
    - Adjust list Repository Contents
    - Fix markdown. =)

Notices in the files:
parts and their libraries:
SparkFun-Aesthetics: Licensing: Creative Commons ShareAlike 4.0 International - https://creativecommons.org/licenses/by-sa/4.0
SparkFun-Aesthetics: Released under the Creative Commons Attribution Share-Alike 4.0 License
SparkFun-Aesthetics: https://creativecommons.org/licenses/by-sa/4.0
